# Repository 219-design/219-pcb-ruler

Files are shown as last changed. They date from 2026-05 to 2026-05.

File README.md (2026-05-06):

# 219 PCB Ruler

The 219 PCB Ruler is a multi-disciplinary tool and development platform. Explore this repository to find inspiration for some of the many ways that this ruler can be built out to help you solve problems and create cool projects.

Want to see the projects we've made so far? Check out the [examples folder](firmware/ruler_lib/examples).

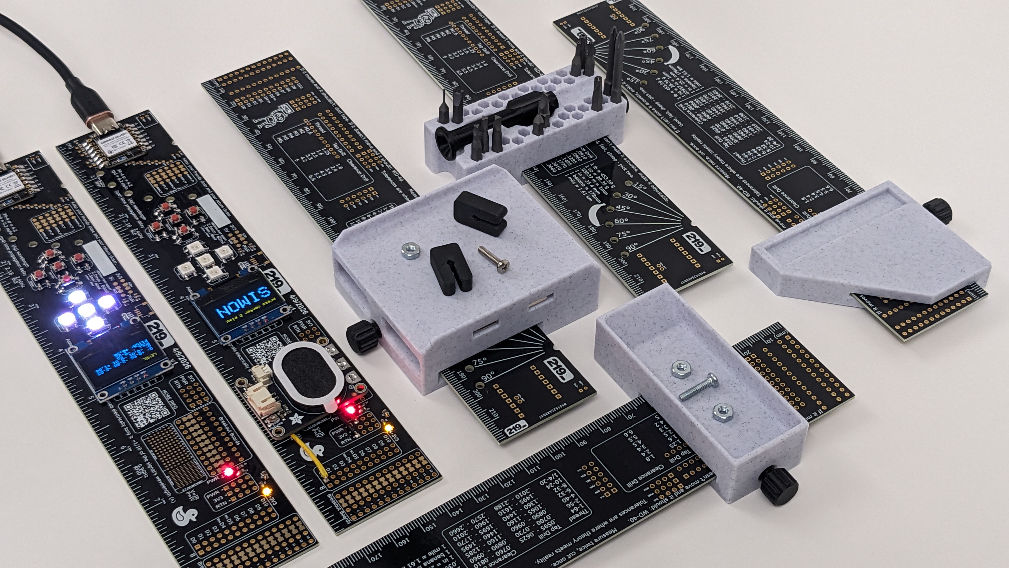
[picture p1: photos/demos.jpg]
Demos


### Known Issues
V1 of the 219 PCB Ruler has the silk screen markings of the battery connector (P17) flipped. BAT+ and BAT- should be swapped. 
Perform a continuity test before using the battery connector to ensure the connections are correct.

## Ways to use the 219 PCB Ruler
### Bare PCB
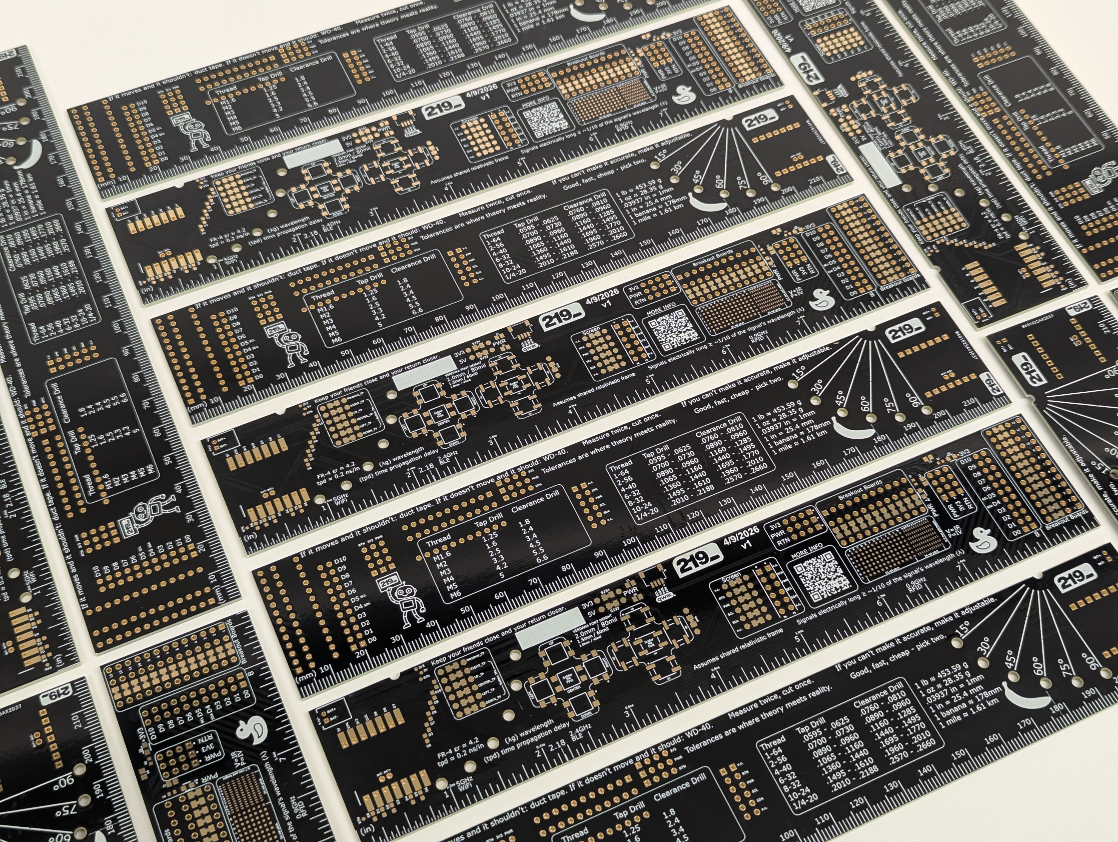
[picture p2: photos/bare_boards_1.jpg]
Bare Boards

- Metric and imperial ruler
- Mechanical and electrical references
- QR code to access additional resources

---

### Electrical Projects
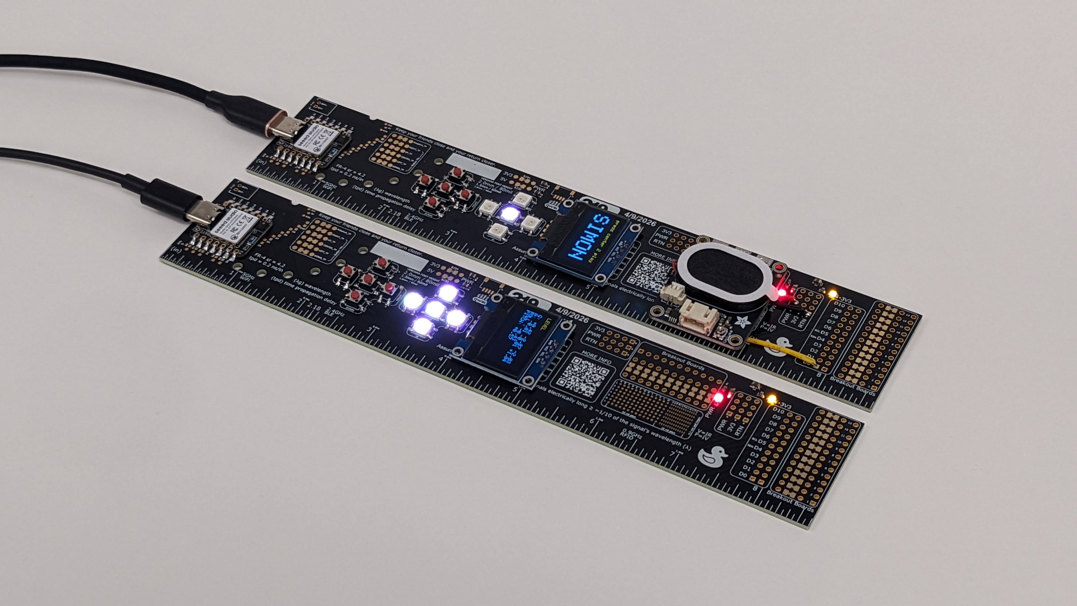
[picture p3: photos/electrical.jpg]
Electrical Demos


Experiment with electronics by soldering on a variety of components to build your own custom projects.  

This board features footprints for:  
- Seeed Studio XIAO Series MCU module  
- Battery connector  
- Button D-pad  
- Neopixels  
- Screen  
- Bypass capacitors  
- Power LEDs  
- QWIIC connector  
- Surface-mount and through-hole protoboard areas  

#### Customization and Flexibility
The board includes **custom solder jumpers** for maximum flexibility.  
- Some jumpers are **normally open**, while others are **normally closed**.  
- These can be used to add series elements or to solder a wire directly to a connection point.  

#### Examples and Resources
Explore our [examples folder](firmware/ruler_lib/examples) for project ideas and wiring diagrams.  

Want to design your own version or order a custom PCB?  
Visit the [electrical folder](electrical) for **Altium design files** and **Gerbers**.  

---

### Mechanical Projects
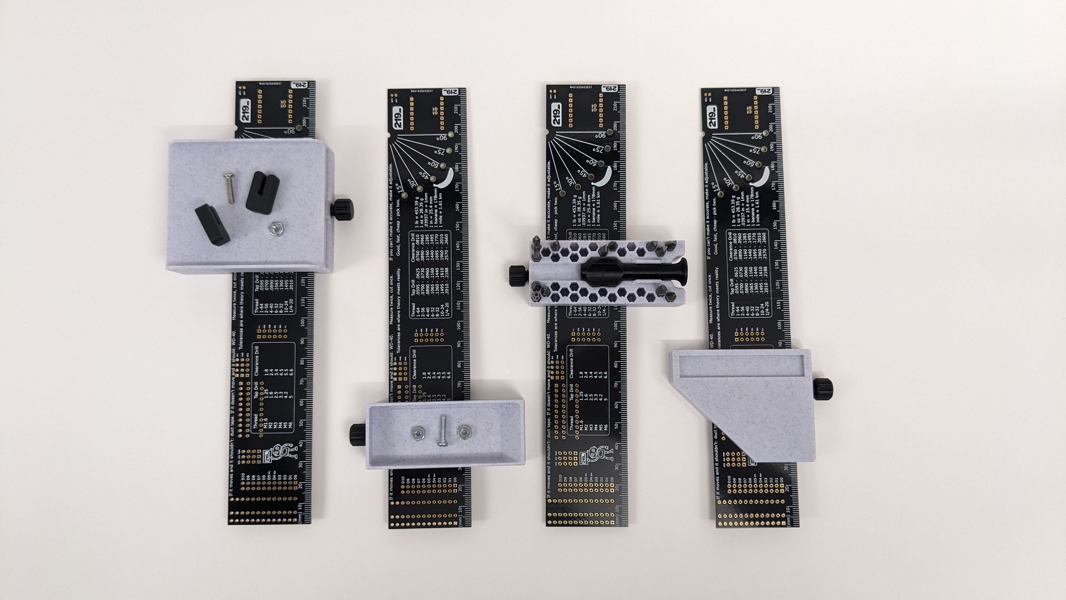
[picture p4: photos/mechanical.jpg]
Mechanical Demos


The PCB ruler is also a great platform for **3D-printed attachments**.  

Weve designed a **3D-printable clamp** that securely grips the ruler and can be adapted for a variety of uses - such as **tool holders**, **marking tools**, or other creative mechanical add-ons.  

Explore our demo designs on [Onshape](https://cad.onshape.com/documents/a66641dbc2e63d92f0bfc751/w/f00ac217e622a64d2a372b85/e/9fa5ab666376091f7bf63026), or browse the [mechanical folder](mechanical) for CAD files and printable models.

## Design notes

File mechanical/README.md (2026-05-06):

# 219 PCB Ruler Mechanical Resources

Explore our demo designs in [Onshape](https://cad.onshape.com/documents/a66641dbc2e63d92f0bfc751/w/f00ac217e622a64d2a372b85/e/9fa5ab666376091f7bf63026). 

Mechanical Demos

This folder is for 3D printable resources and assembly instructions for add-ons to the PCB ruler.

Looking for a design related to an interdisciplinary project? Check out the [examples folder](../firmware/ruler_lib/examples).

---

The PCB ruler is also a great platform for **3D-printed attachments**.  

We've designed a **3D-printable clamp** that securely grips the ruler and can be adapted for a variety of uses - such as **tool holders**, **marking tools**, or other creative mechanical add-ons.  

## Demo Photos
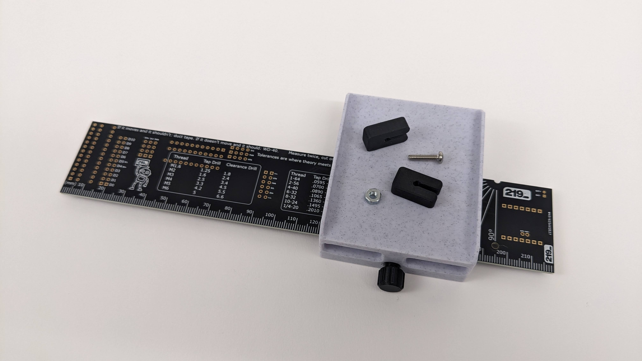
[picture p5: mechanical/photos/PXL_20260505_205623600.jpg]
Storage Large

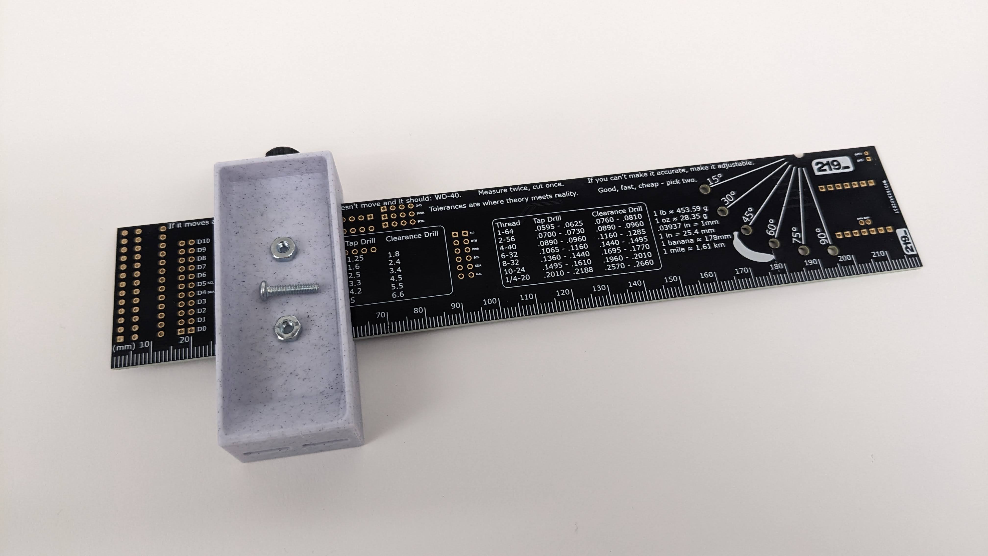
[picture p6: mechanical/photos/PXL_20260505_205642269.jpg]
Storage Small

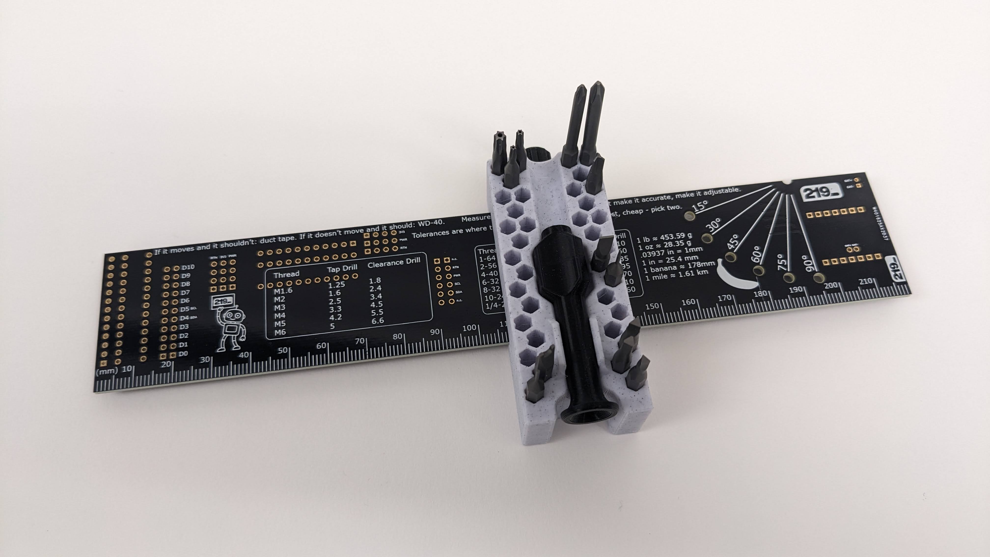
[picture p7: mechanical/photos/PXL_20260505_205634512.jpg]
Screw Driver

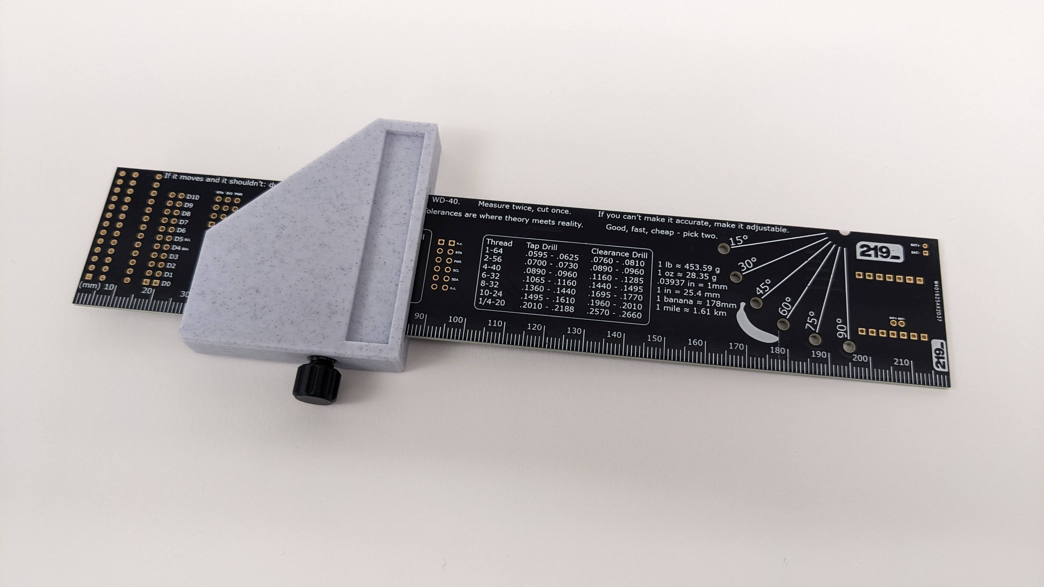
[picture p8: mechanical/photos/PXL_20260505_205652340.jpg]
Marking Tool


## CAD Photos
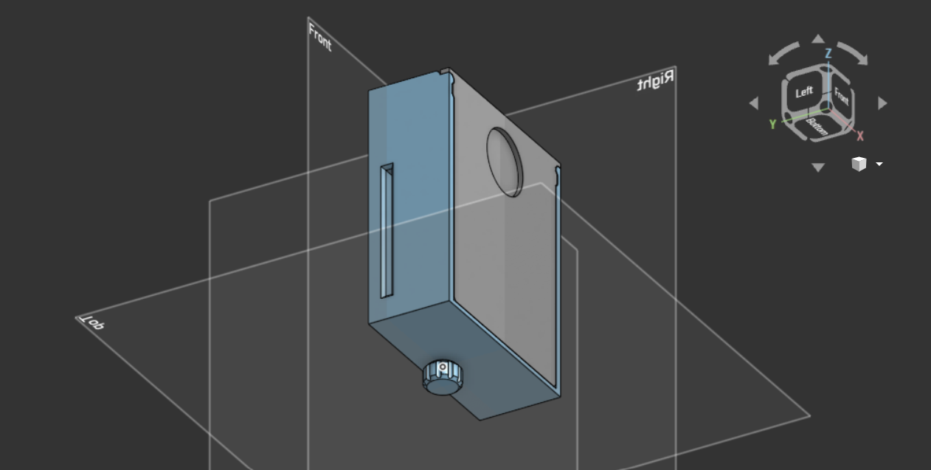
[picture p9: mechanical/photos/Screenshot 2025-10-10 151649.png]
CAD Photo 1

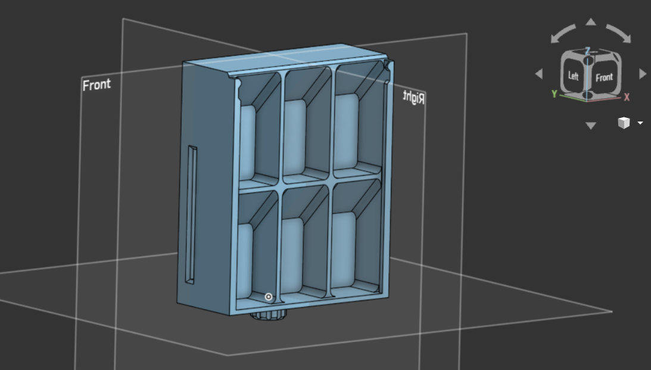
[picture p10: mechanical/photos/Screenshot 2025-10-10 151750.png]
CAD Photo 2

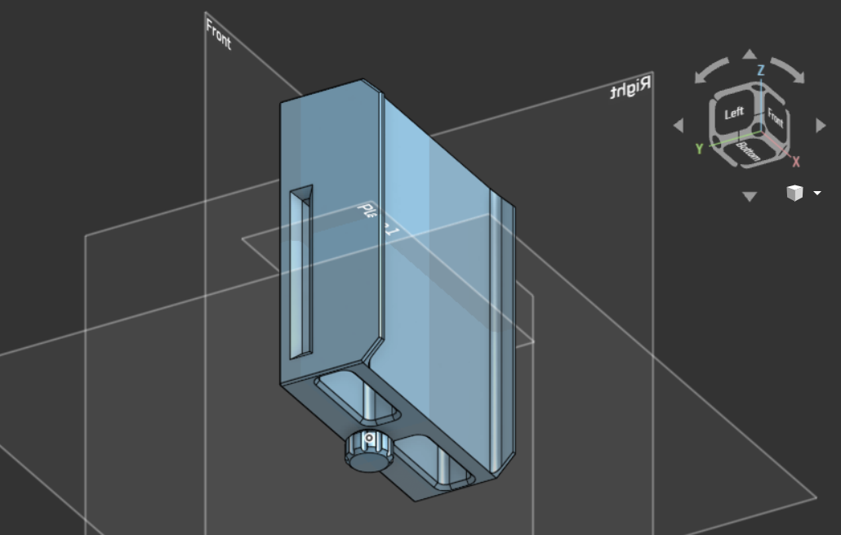
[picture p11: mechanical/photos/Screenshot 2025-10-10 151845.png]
CAD Photo 3

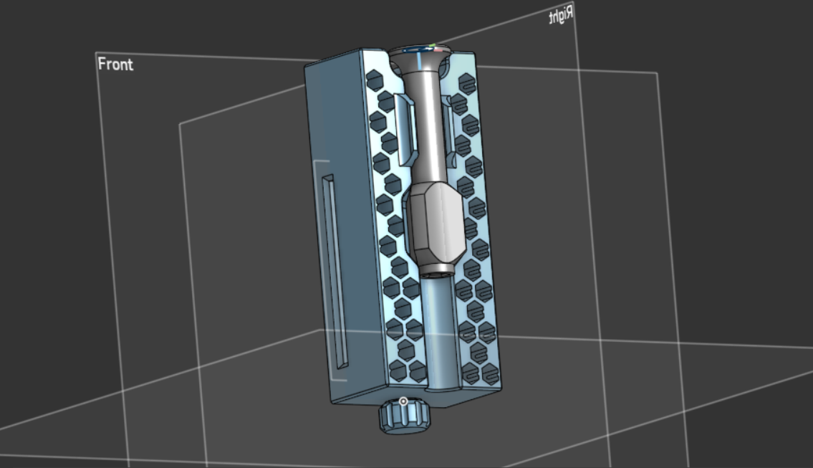
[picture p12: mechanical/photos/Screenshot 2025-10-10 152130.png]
CAD Photo 4

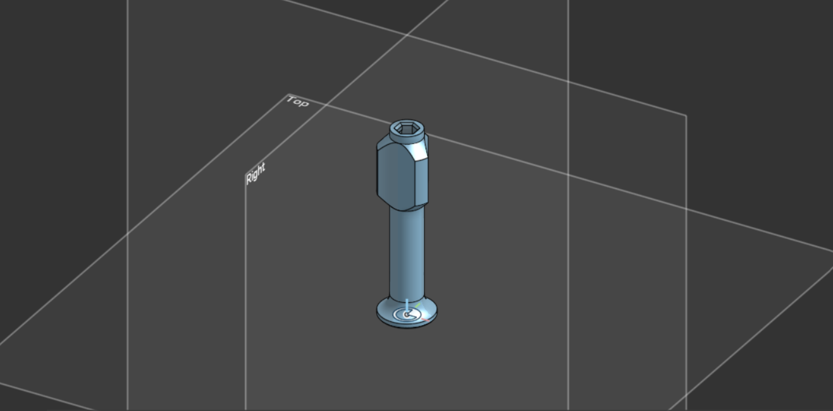
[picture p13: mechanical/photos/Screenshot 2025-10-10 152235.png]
CAD Photo 5

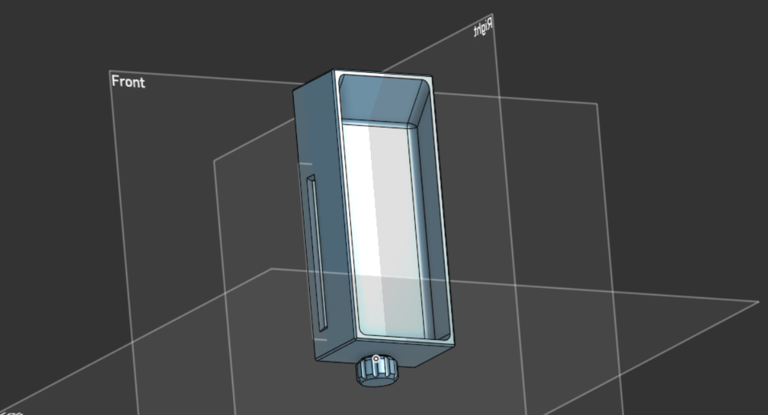
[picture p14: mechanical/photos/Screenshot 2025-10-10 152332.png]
CAD Photo 6


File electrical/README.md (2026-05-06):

# 219 PCB Ruler Electrical Resources
This folder contains everything you need to order, build, and debug the board yourself.

Interested in a specific project? Check out the [examples folder](../firmware/ruler_lib/examples)

### Electrical Projects
Electrical Demos

Experiment with electronics by soldering on a variety of components to build your own custom projects.  

This board features footprints for:  
- Seeed Studio XIAO Series MCU module  
- Battery connector  
- Button D-pad  
- Neopixels  
- Screen  
- Bypass capacitors  
- Power LEDs  
- QWIIC connector  
- Surface-mount and through-hole protoboard areas  

#### Customization and Flexibility
The board includes **custom solder jumpers** for maximum flexibility.  
- Some jumpers are **normally open**, while others are **normally closed**.  
- These can be used to add series elements or to solder a wire directly to a connection point.  

### Assembly
So you have a 219 PCB Ruler and you want to make a cool electrical design. Where do you start?

The board is designed to be used with a [Seeed Studio XIAO Series MCU module](https://www.seeedstudio.com/xiao-series-page).
These modules are all pin compatible, so pick which one has the features you want for your project.
Mount the module to the U1 footprint. The footprint includes options to surface mount solder, TH solder, or TH socket the module. Choose what is best for your project.

Check out the BOM for part recommendations. Check the examples folder for demo specific BOMs.

#### Bypass caps
The board has four footprints (C1-C4) for bypass caps to provide some localized power.

#### Power LEDs
The board has two power LEDs: 5V (D1) and 3V3 (D2). Recommend installing these and their associated current limiting resistors (R1, R2).

#### Want to use use a LiPo battery?
Surface mount solder the MCU to U1 so the BAT- and BAT+ TH pins touch the pads on the bottom of the module.
Solder a connector to P17 and flow solder through the BAT- and BAT+ TH pads to connect the pads to the pads on the bottom of the MCU module.
Choose a battery that meets your project specs and make sure the pinout matches the connector.
Note: the silk screen label for the battery connector on v1 is flipped. See [Known Issues](../README.md#known-issues).

#### Want to use buttons?
Solder buttons to as many of the D-pad button pads as you would like. Make sure to solder the center button first if you want to use it since it will be harder to solder it after installing the outer buttons.
The buttons short to return on press. The circuit doesn't include a pull up or debouncing circuit so recommend implementing this in firmware.

#### Want to use Neopixels?
Solder Neopixels to as many of the pads as you would like (U2, U3, U4, U5, U6). Note that Neopixels works on single wire communication and ours are connected in numerical order. So if you would like to use only one Neopixel, use U2. Otherwise you will need to short the input and output pins across the unused Neopixels in the chain before the one you want to use in order for the signal to reach a pad later in the chain.

#### Want to use a Screen?
Ideally pick a screen with a pinout that matches the silk on the board. See the BOM for the one we used.
If you have a different I2C screen that you would like to use but it has a different pinout for it's 100mil header, you can reconfigure the pinout by cutting the custom jumpers under the pin. Then use the surface mount or through hole pads to wire up the correct pinout with some jumper wire.
Solder your screen into either P8 or P9. 

#### Want to use a QWIIC module?
Solder a QWIIC connector to J1 and plug in any QWIIC module. This footprint is already wired up to power and I2C so it is ready to go.

#### Have a 100mil header sensor module?
There are two 100mil header breakout board sections on the board. Just solder your module to the last row of TH headers and then solder a wire from either side of the custom jumper to the desired power, return, or IO pins.
See our demos for an examples of this.

#### Have other parts?
Use one of the three breakout areas to solder TH or SMT components. Use jumper wire to connect the pins to the appropriate IO and power signals.

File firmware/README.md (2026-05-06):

# ME218 PCB Ruler Firmware Resources
This folder contains firmware examples for basic component functionality.

## Ruler Lib

The Ruler Lib is small collection of classes for using some of the hardware features of the ruler board. 

### Installing Ruler Lib

Open the Arduino IDE. 

Select: Sketch Menu >> Include Library >> Add .ZIP library...

In the file dialog, find the ruler_lib.zip file

This will install the ruler_lib to use with sketches

### Editing the Ruler Lib

If you'd like to make changes to the lib, you can modify the files in the src folder. Then compress the entire "ruler_lib" directory into a zip file and (re)install the new library from zip as described above.

### Included Examples

All examples in this repository are included in the Arduino IDE when the Ruler Lib is installed. To open an example from the IDE, such as the Simon Game example:

Select: File >> Examples >> ruler_lib >> simon_says

Any dependent libraries are noted with the github repository in the example code.

### Seed XIAO Boards 

Install Seed XIAO Board packages as instructed by:
https://wiki.seeedstudio.com/XIAO_BLE/#getting-started

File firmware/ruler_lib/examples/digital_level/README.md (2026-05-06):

# ME218 PCB Ruler - Digital Level 

This sketch creates a digital level, utilizing the IMU on the XIAO-nRF52840 board. Gyroscope and accelerometer readings are displayed on the OLED screen, along with roll and pitch angles. A complementary filter is used for approximation of pitch/roll angles. The LEDs will indicate white for levelness in the appropriate direction, and a graduated scale of color (purple to red) for the direction of positive slope.

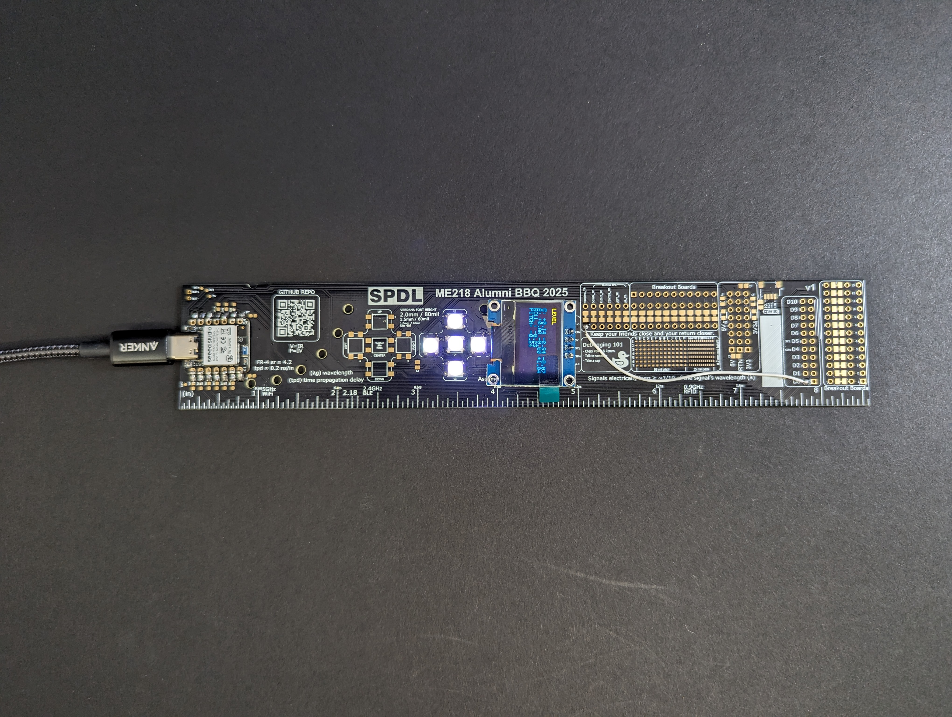
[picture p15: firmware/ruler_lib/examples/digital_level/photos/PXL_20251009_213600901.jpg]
level


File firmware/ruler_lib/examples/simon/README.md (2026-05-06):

# ME218 PCB Ruler - Simon

This sketch is a working example of the Simon game by Milton Bradley (now Hasbro). 
Simon is a registered trademark of Hasbro, Inc. This project is not affiliated with or endorsed by Hasbro.

The game begins by pressing the center button. Each round, a colored led will light and the associated tone will play. The player then copies the pattern by pressing the button associated with the led.
The next round will play back the previous light, along with another one. The player copies the pattern again, adding in the new one at the end.
As rounds go by, the speed of the pattern presentation will increase. There are 30 rounds of play. If the player enters an incorrect entry, the game is over.

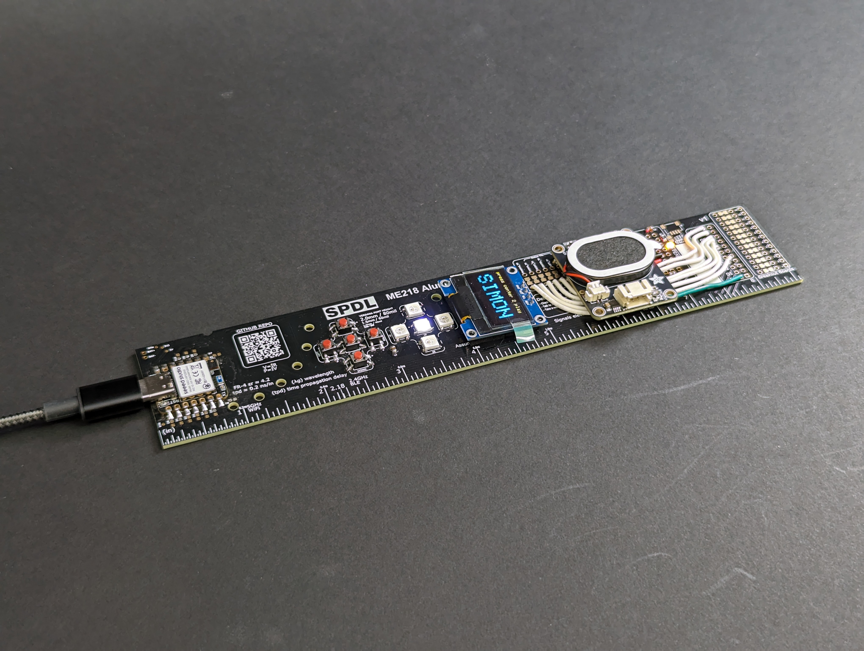
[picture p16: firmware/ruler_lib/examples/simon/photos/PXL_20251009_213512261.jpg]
simon


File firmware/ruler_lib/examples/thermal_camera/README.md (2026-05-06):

# 219 PCB Ruler - Thermal Camera - COMING SOON

This sketch creates a thermal camera utilizing a thermal sensor and 1.44" tft. This sketch was extended from Adafruit's examples for their AMG88xx GridEYE 8x8 IR camera but made to work with a different tft display. 

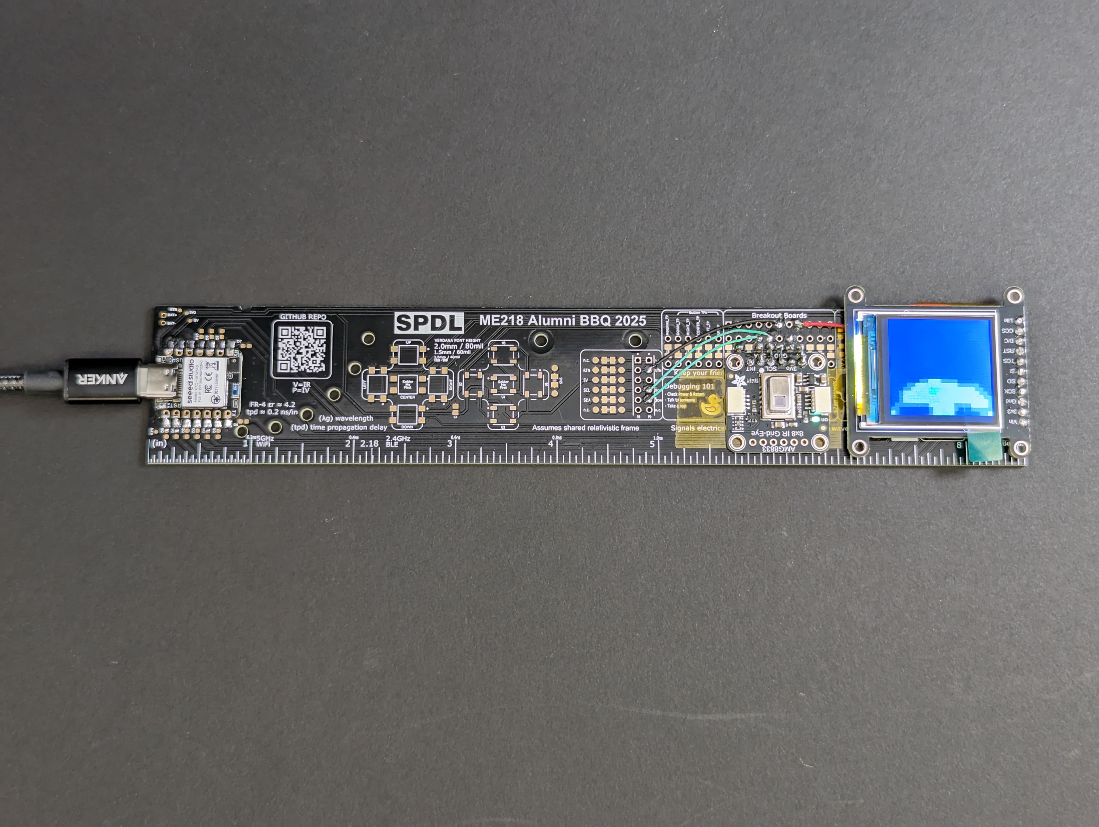
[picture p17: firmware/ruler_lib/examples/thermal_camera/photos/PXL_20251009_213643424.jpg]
thermal


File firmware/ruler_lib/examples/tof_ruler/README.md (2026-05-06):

# 219 PCB Ruler - ToF Ruler - COMING SOON

This sketch creates line of sight digital ruler utilizing a time of flight sensor. Distances measured from the sensor will be displayed on the OLED screen. Pressing the button will change units from imperial to metric. Distances greater than 5400mm are outside of the sensors operating range and will not be accurate.

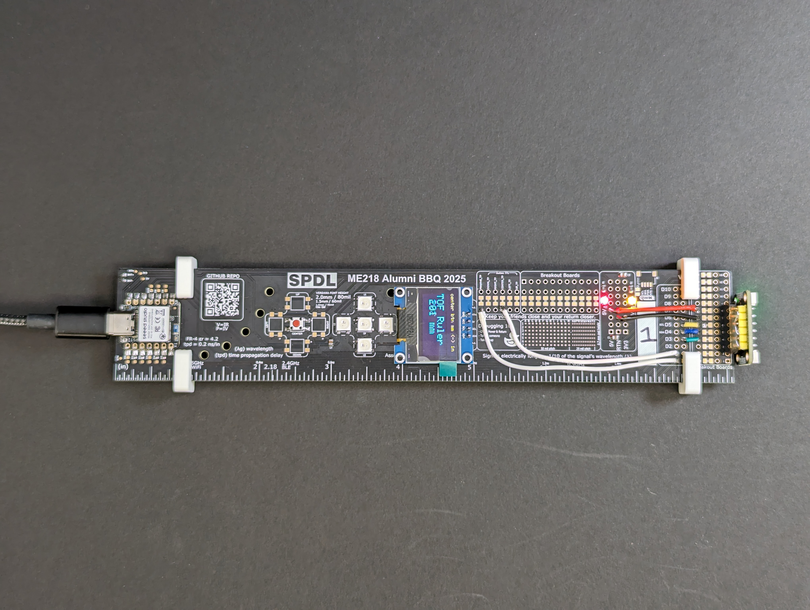
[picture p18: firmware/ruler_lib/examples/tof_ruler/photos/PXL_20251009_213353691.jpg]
tof


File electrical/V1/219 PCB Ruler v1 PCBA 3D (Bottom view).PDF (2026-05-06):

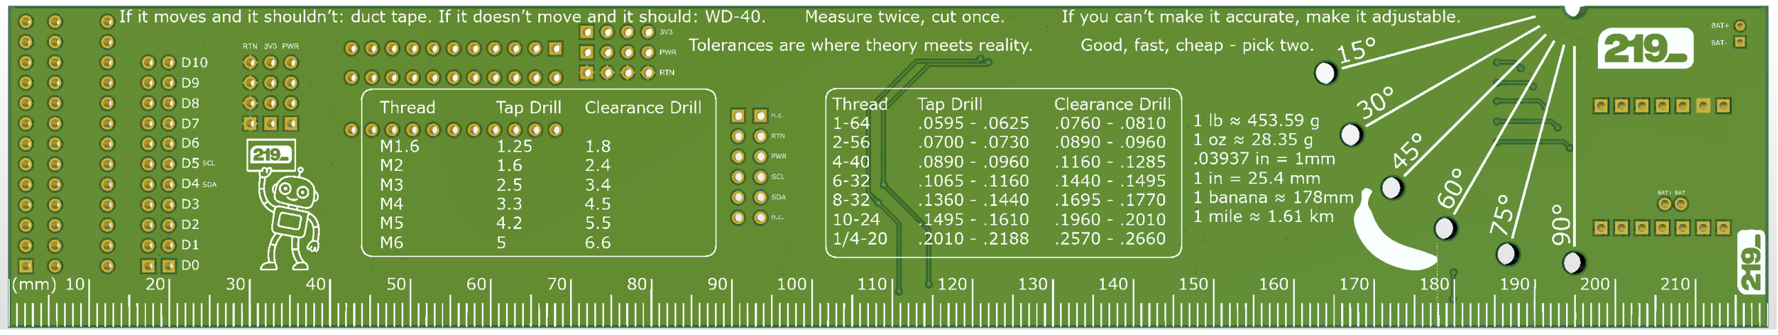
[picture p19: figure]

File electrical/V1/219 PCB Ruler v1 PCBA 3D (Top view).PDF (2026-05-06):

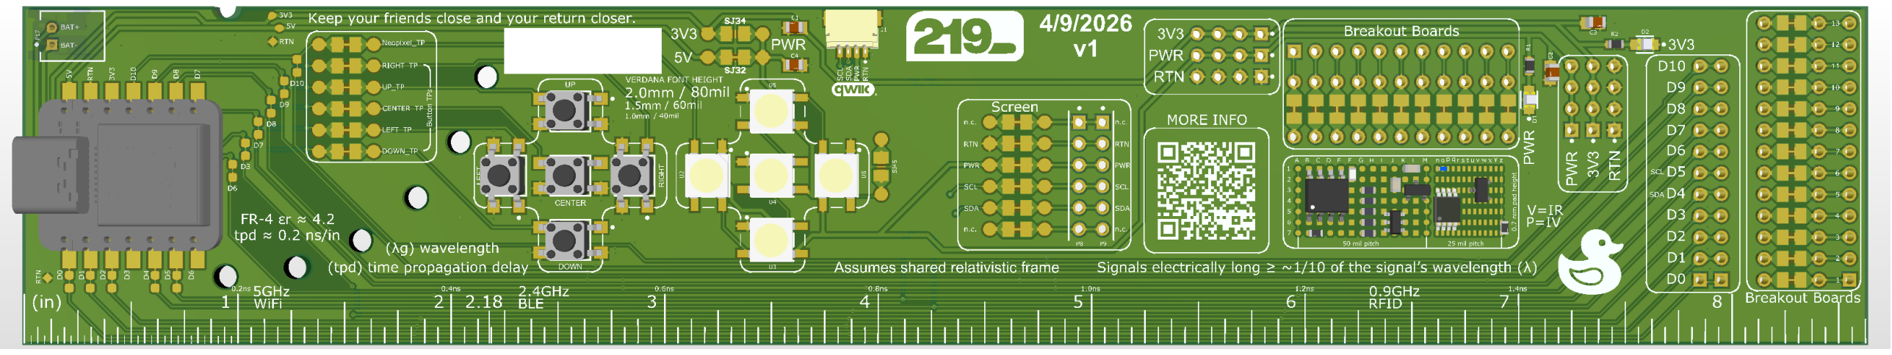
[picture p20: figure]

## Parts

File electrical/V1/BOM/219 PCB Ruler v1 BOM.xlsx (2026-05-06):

 | Bill of Materials
 | Project Name: | 219 PCB Ruler
 | Report Date: | 4/9/2026 | 15:21
 | Engineer: | 219 Design
 | BOM Revision History
 | Version | Date | Description
 | v1 | 4/9/2026 | Initial release
# | Designator | Description | Manufacturer 1 | Manufacturer Part Number 1 | Supplier 1 | Supplier Part Number 1 | Fitted | Footprint | Quantity
1 | R1, R2 | SMD Chip Resistor, 330 Ohm, ± 1%, 100 mW, 0603 [1608 Metric], Thick Film, General Purpose | Yageo Group | RC0603FR-07330RL | DigiKey | 311-330HRCT-ND | Fitted | RESC1608X55X25NL10T15 | 2
2 | U2-U6 | NeoPixel 5050 RGB LED with Integrated Driver Chip - 10 Pack | Adafruit Industries 1655 | Adafruit Industries | 1655 | DigiKey | 1528-1104-ND | Fitted | ADA-RGB-1655_V | 5
3 | C1-C4 | Multilayer Ceramic Capacitor, 1 uF, 50 V, ± 10%, X7R, 0805 [2012 Metric] | Murata | GCM21BR71H105KA03K | DigiKey | 490-13310-1-ND | Fitted | FP-GRM21B-0_15-IPC_B | 4
4 | D1 | 0805 Single Color LED, Super Red, Colorless Diffused, 1.3mm | Osram | LS R976-NR-1 | Mouser | 720-LSR976-NR-1 | Fitted | FP-LS_R976-MFG | 1
5 | D2 | 0805 Single Color LED, Yellow, Colorless Diffused, 1.3mm | Osram | LY R976-PS-36 | Mouser | 720-LYR976-PS-36 | Fitted | FP-LS_R976-MFG | 1
6 | CENTER, DOWN, LEFT, RIGHT, UP | Keypad Switch, 1 Switches, SPST, Momentary-tactile, 0.05A, 12VDC, 2.45N, Solder Terminal, Surface Mount-straight | E-Switch | TL3305AF260QG | DigiKey | EG5353CT-ND | Fitted | FP-TL3305AF260QG-MFG | 5
7 | P17 | Header for PCB; pitch 2.00mm; 2-contacts; THT; male; side entry; 100V/2A | JST | S2B-PH-K-S(LF)(SN) | Newark | S2B-PH-K-S (LF)(SN) | Fitted | JST-S2B-PH-K-S_V | 1
8 | U1 | Seeed studio XIAO series dev boards | Seeed Studio | 102010428 | DigiKey | 1597-102010428-ND | Fitted | Seeeduino XIAO-Footprint-Both | 1
9 | J1 | QWIIC JST CONNECTOR - SMD 4-PIN | SparkFun | 14417 | DigiKey | 1568-14417-ND | Fitted | SPARKFUN_PRT-14417 | 1
10 | P8 | Screen | ELEGOO | EL-SM-008 | Amazon | EL-SM-008 | Fitted | HDR 06 POS 100mil 2.54mm | 1
 |  |  |  |  |  |  |  |  | 22
Notes

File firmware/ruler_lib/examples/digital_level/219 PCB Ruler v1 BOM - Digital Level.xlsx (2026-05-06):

 | Bill of Materials
 | Project Name: | 219 PCB Ruler
 | Report Date: | 5/4/2026 | 17:09
 | Engineer: | 219 Design
 | BOM Revision History
 | Version | Date | Description
 | v1 | 5/4/2026 | Initial release
# | Designator | Description | Manufacturer 1 | Manufacturer Part Number 1 | Supplier 1 | Supplier Part Number 1 | Fitted | Footprint | Quantity
1 | C1-C4 | Multilayer Ceramic Capacitor, 1 uF, 50 V, ± 10%, X7R, 0805 [2012 Metric] | Murata | GCM21BR71H105KA03K | DigiKey | 490-13310-1-ND | Fitted | FP-GRM21B-0_15-IPC_B | 4
2 | CENTER, DOWN, LEFT, RIGHT, UP | Keypad Switch, 1 Switches, SPST, Momentary-tactile, 0.05A, 12VDC, 2.45N, Solder Terminal, Surface Mount-straight | E-Switch | TL3305AF260QG | DigiKey | EG5353CT-ND | Not Fitted | FP-TL3305AF260QG-MFG | 0
3 | D1 | 0805 Single Color LED, Super Red, Colorless Diffused, 1.3mm | Osram Opto | LS R976-NR-1 | Mouser | 720-LSR976-NR-1 | Fitted | FP-LS_R976-MFG | 1
4 | D2 | 0805 Single Color LED, Yellow, Colorless Diffused, 1.3mm | Osram | LY R976-PS-36 | Mouser | 720-LYR976-PS-36 | Fitted | FP-LS_R976-MFG | 1
5 | J1 | QWIIC JST CONNECTOR - SMD 4-PIN | SparkFun | 14417 | DigiKey | 1568-14417-ND | Not Fitted | SPARKFUN_PRT-14417 | 0
6 | P17 | Header for PCB; pitch 2.00mm; 2-contacts; THT; male; side entry; 100V/2A | JST | S2B-PH-K-S(LF)(SN) | Future Electronics | 7754757 | Not Fitted | JST-S2B-PH-K-S_V | 0
7 | R1, R2 | SMD Chip Resistor, 330 Ohm, ± 1%, 100 mW, 0603 [1608 Metric], Thick Film, General Purpose | Yageo Group | RC0603FR-07330RL | DigiKey | 311-330HRCT-ND | Fitted | RESC1608X55X25NL10T15 | 2
8 | U1 | Seeed studio XIAO series dev boards | Seeed Studio | XIAO nRF52840 Sense | DigiKey | 1597-102010469-ND | Fitted | Seeeduino XIAO-Footprint-Both | 1
9 | U2-U6 | NeoPixel 5050 RGB LED with Integrated Driver Chip - 10 Pack | Adafruit Industries 1655 | Adafruit Industries | 1655 | DigiKey | 1528-1104-ND | Fitted | ADA-RGB-1655_V | 5
10 | P8 | Screen | ELEGOO | EL-SM-008 | Amazon | EL-SM-008 | Fitted | HDR 06 POS 100mil 2.54mm | 1
11 | NA | Jumper wire | Sparkfun | 11367 | DigiKey | 1568-11367-ND | Fitted | NA | 1
 |  |  |  |  |  |  |  |  | 16
Notes

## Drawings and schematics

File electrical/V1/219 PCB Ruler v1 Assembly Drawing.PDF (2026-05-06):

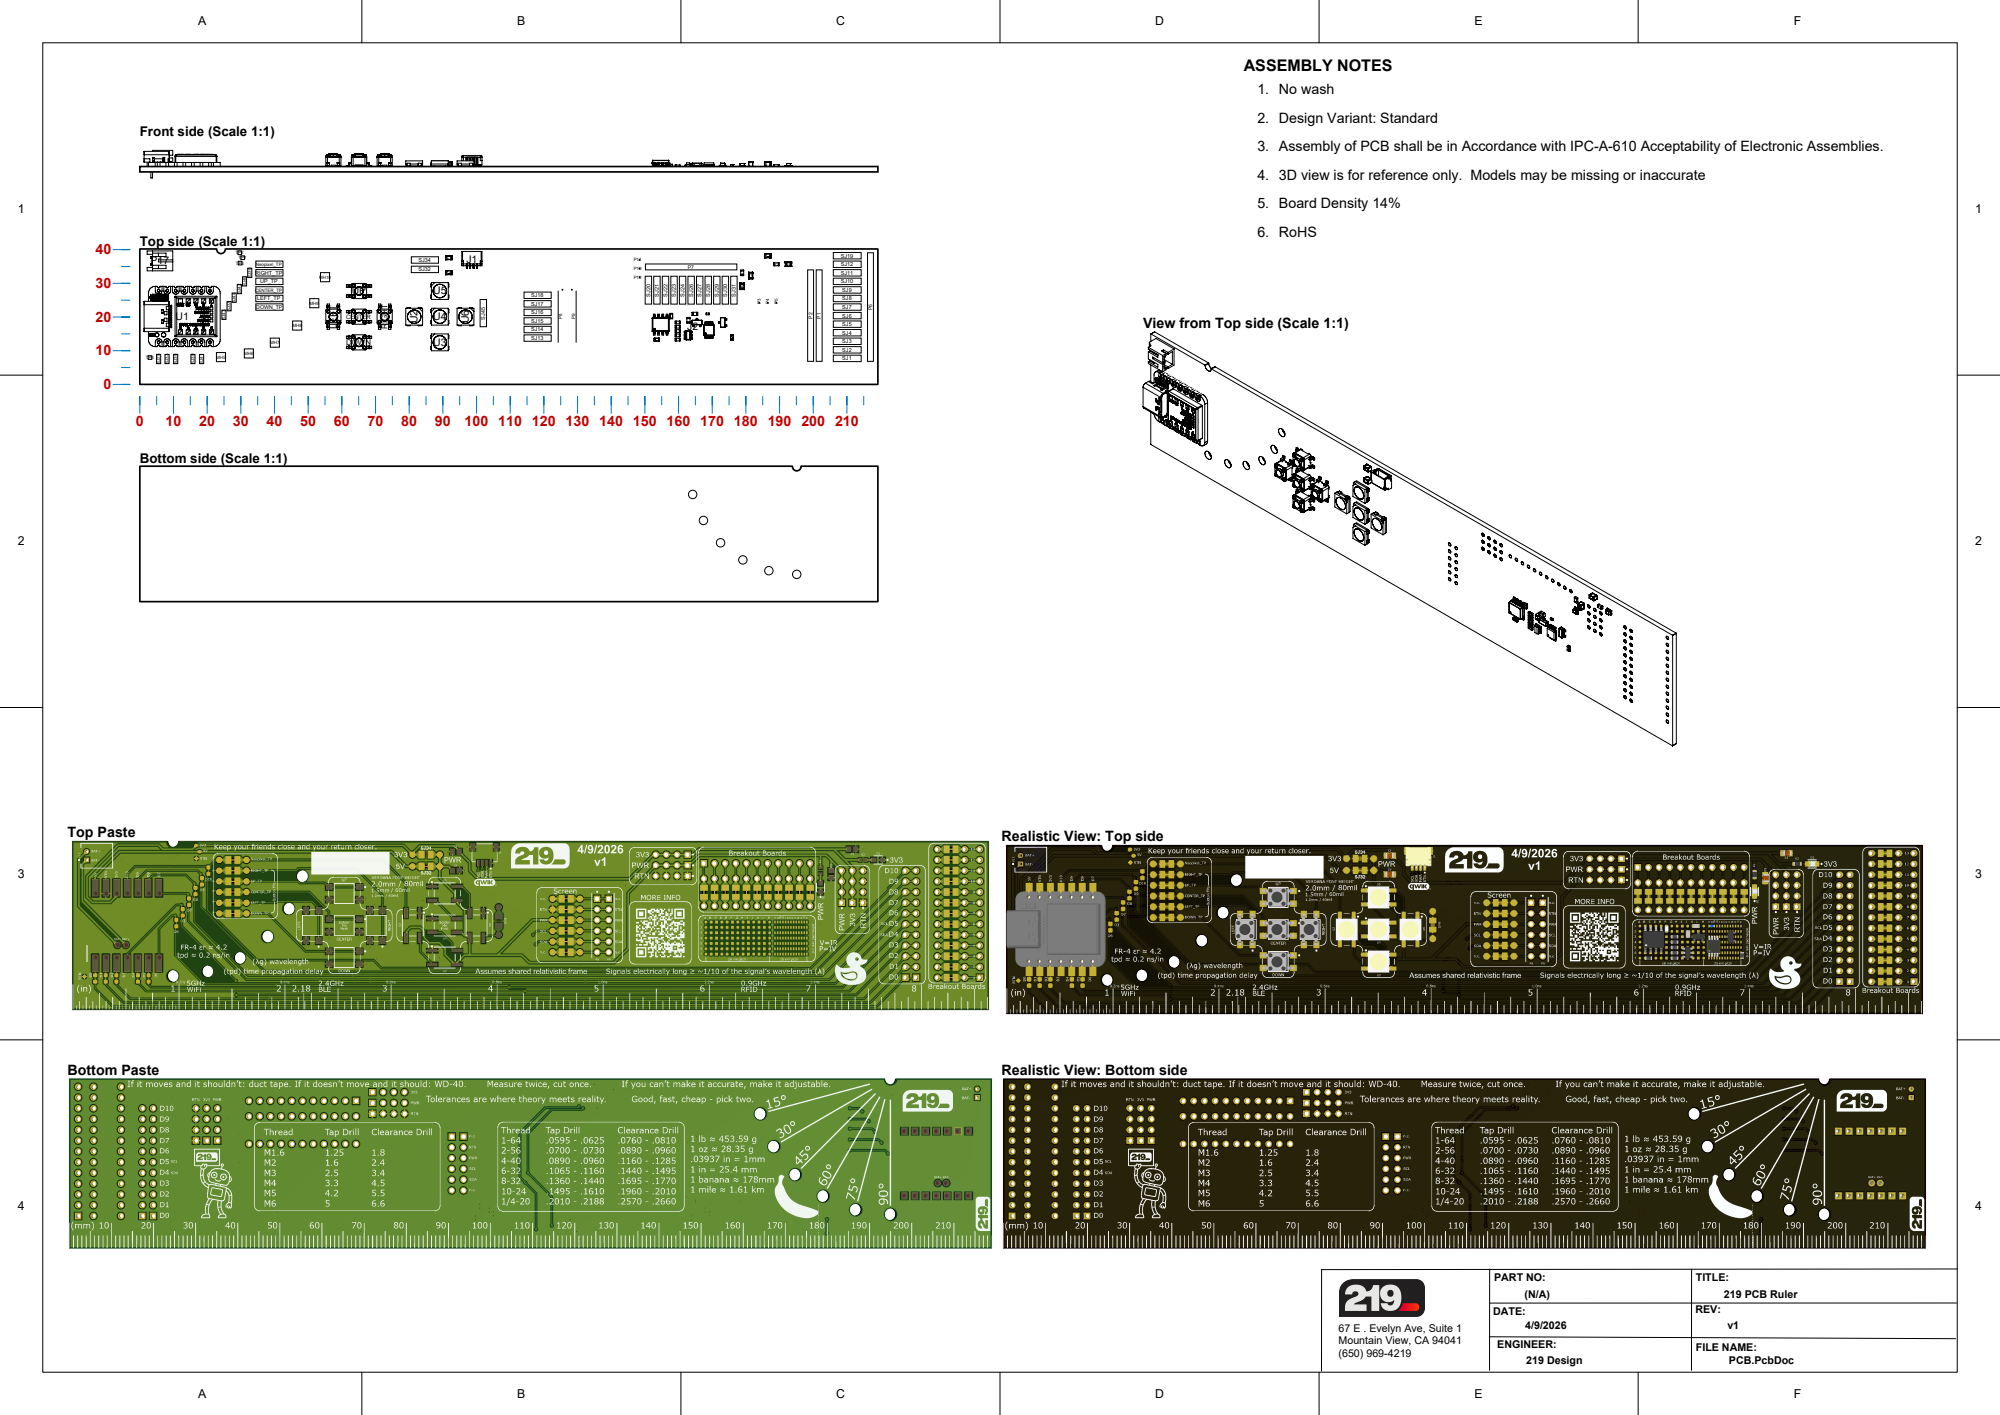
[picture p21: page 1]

ASSEMBLY NOTES
1. No wash
2. Design Variant: Standard
3. Assembly of PCB shall be in Accordance with IPC-A-610 Acceptability of Electronic Assemblies.
4. 3D view is for reference only. Models may be missing or inaccurate
5. Board Density 14%
6. RoHS

View from Top side (Scale 1:1)

Realistic View: Bottom side

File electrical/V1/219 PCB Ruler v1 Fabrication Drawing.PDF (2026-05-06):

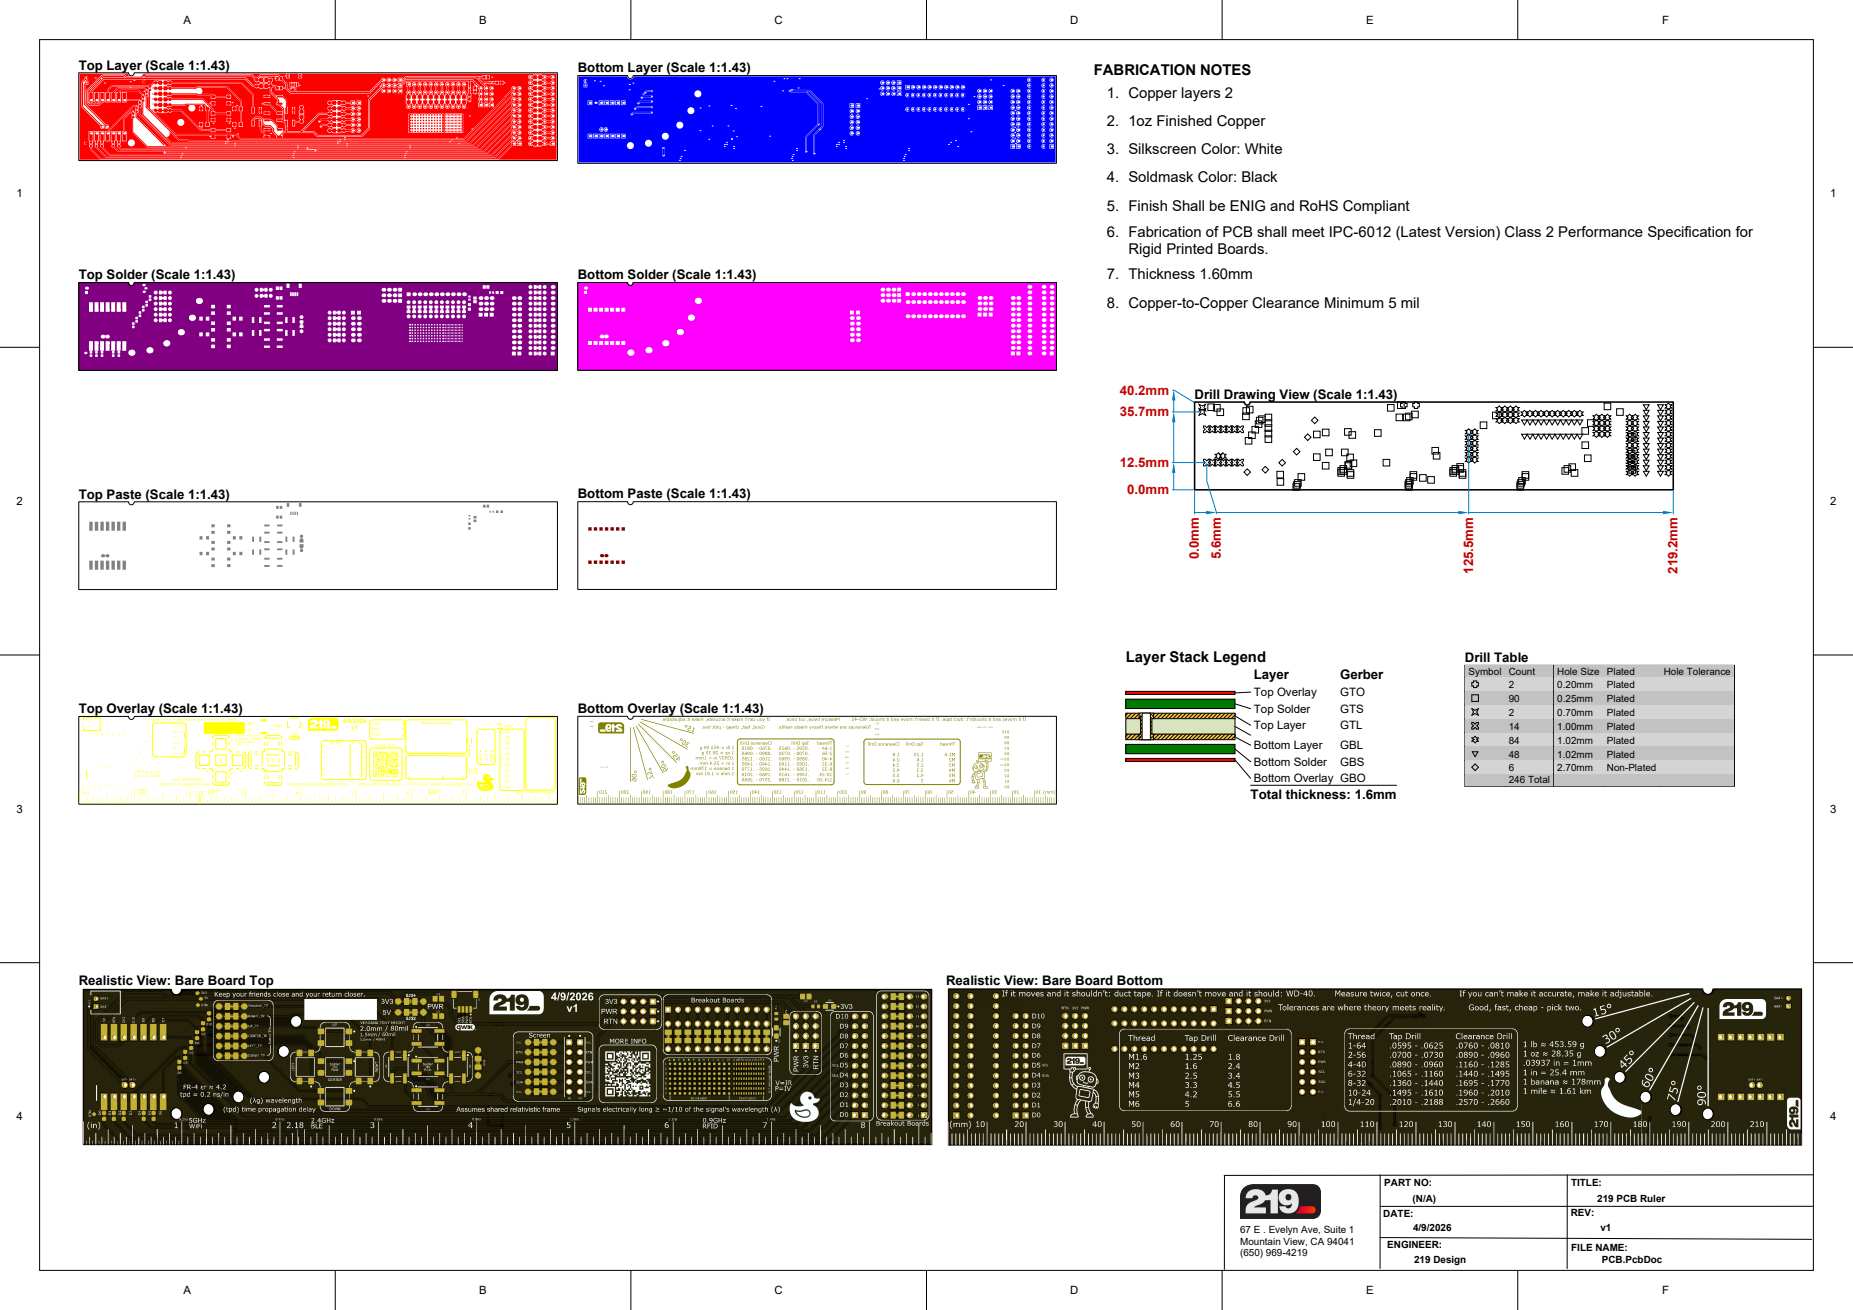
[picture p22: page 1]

FABRICATION NOTES
1. Copper layers 2
2. 1oz Finished Copper
3. Silkscreen Color: White
4. Soldmask Color: Black
5. Finish Shall be ENIG and RoHS Compliant
Fabrication of PCB shall meet IPC-6012 (Latest Version) Class 2 Performance Specification for
Rigid Printed Boards.
7. Thickness 1.60mm
8. Copper-to-Copper Clearance Minimum 5 mil

Drill Drawing View (Scale 1:1.43)

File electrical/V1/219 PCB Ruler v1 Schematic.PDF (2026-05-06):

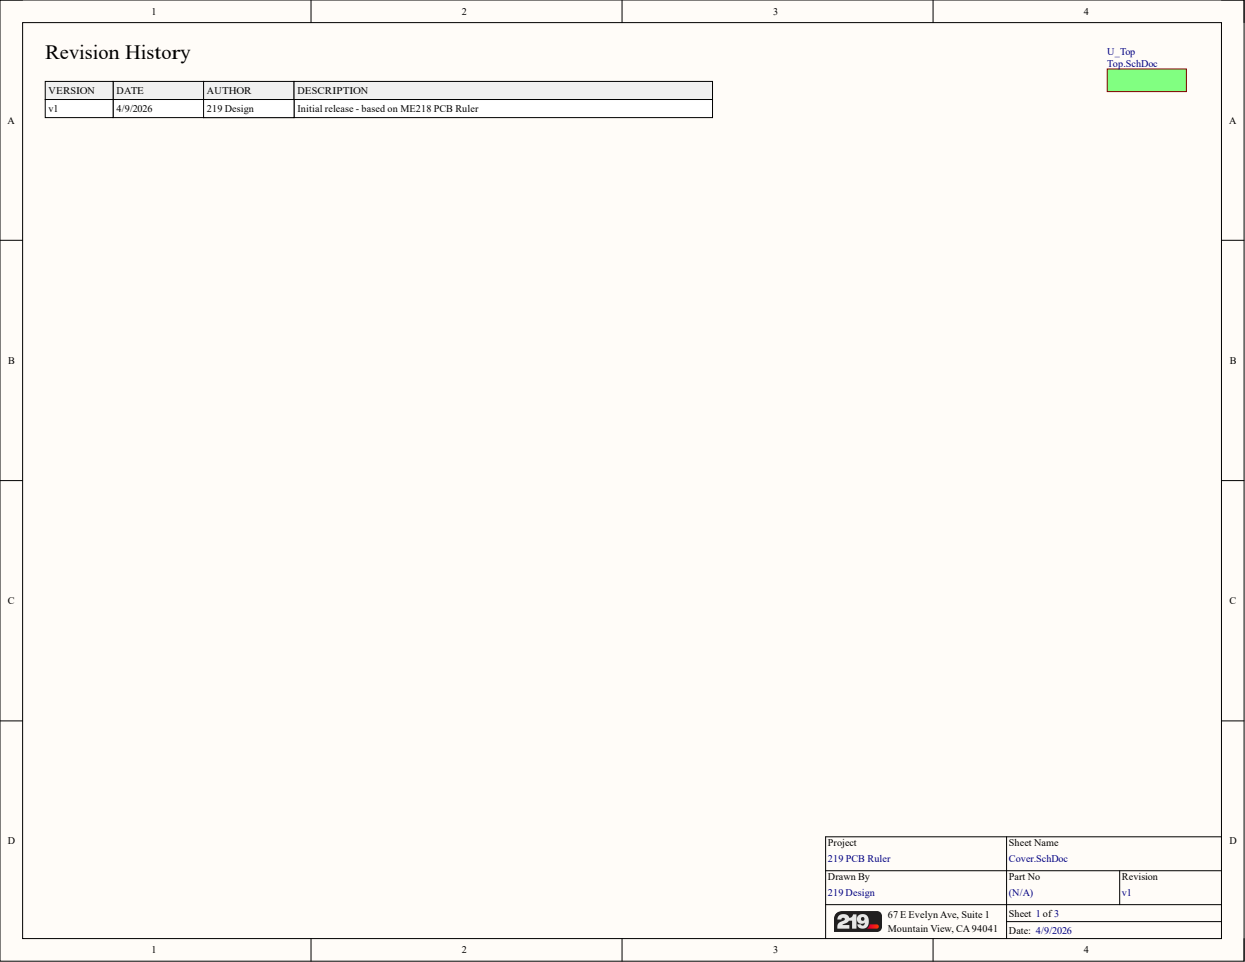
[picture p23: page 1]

VERSION | DATE | AUTHOR | DESCRIPTION
v1 | 4/9/2026 | 219 Design | Initial release - based on ME218 PCB Ruler

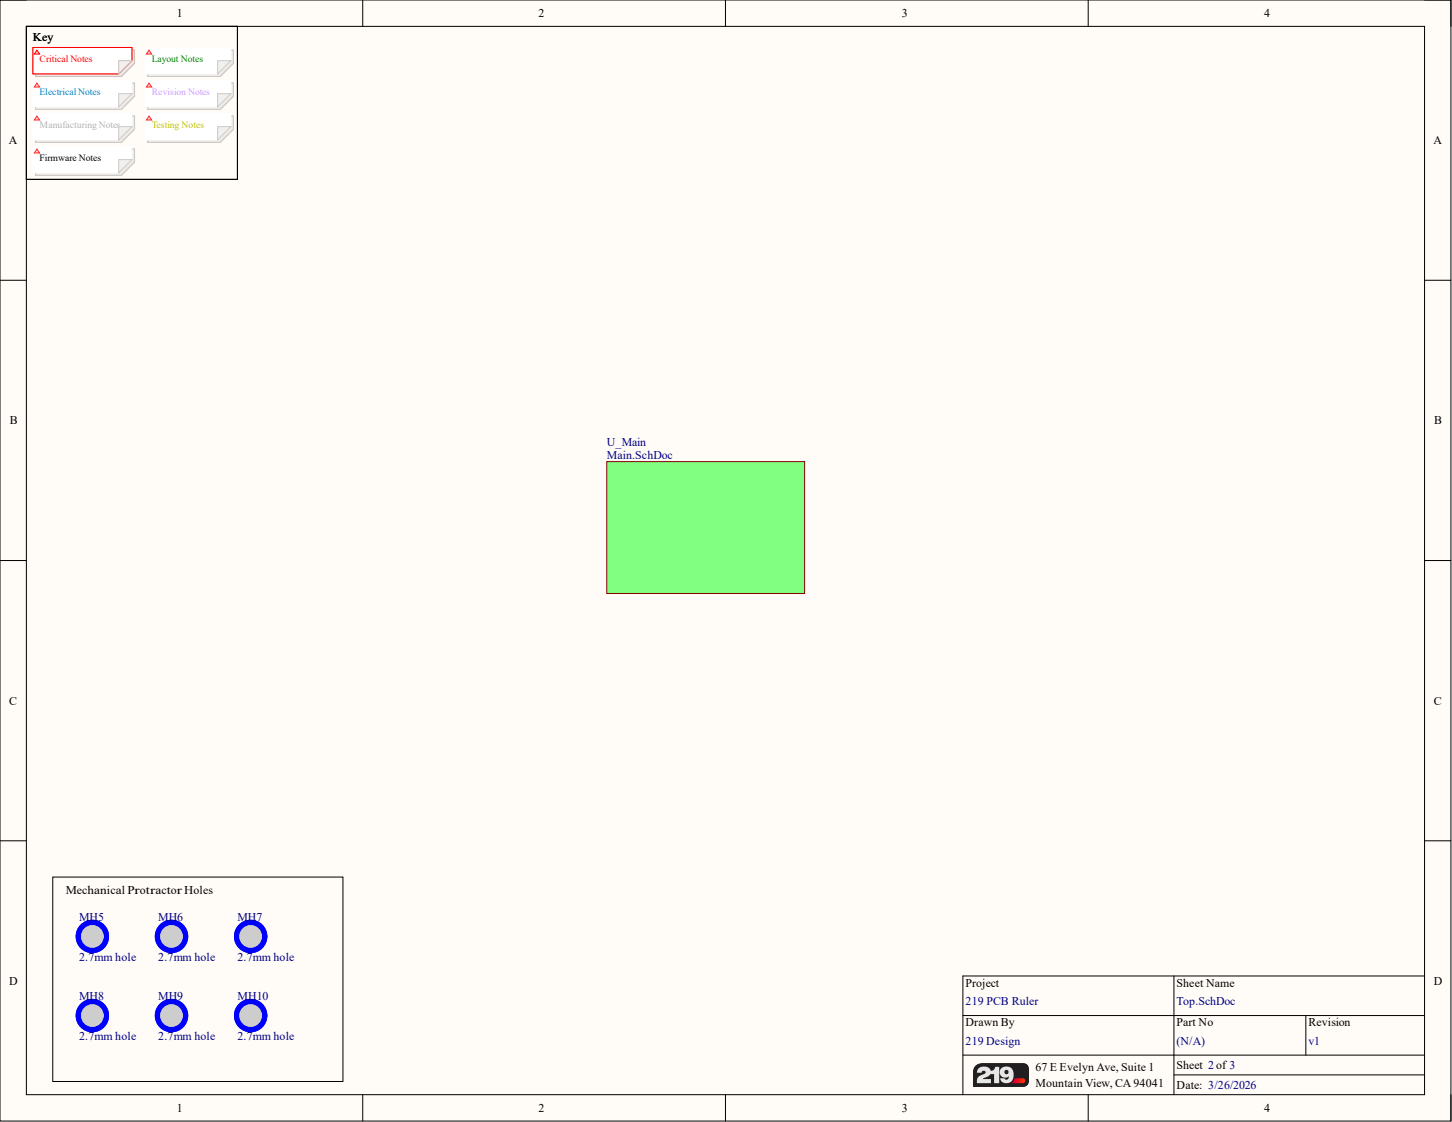
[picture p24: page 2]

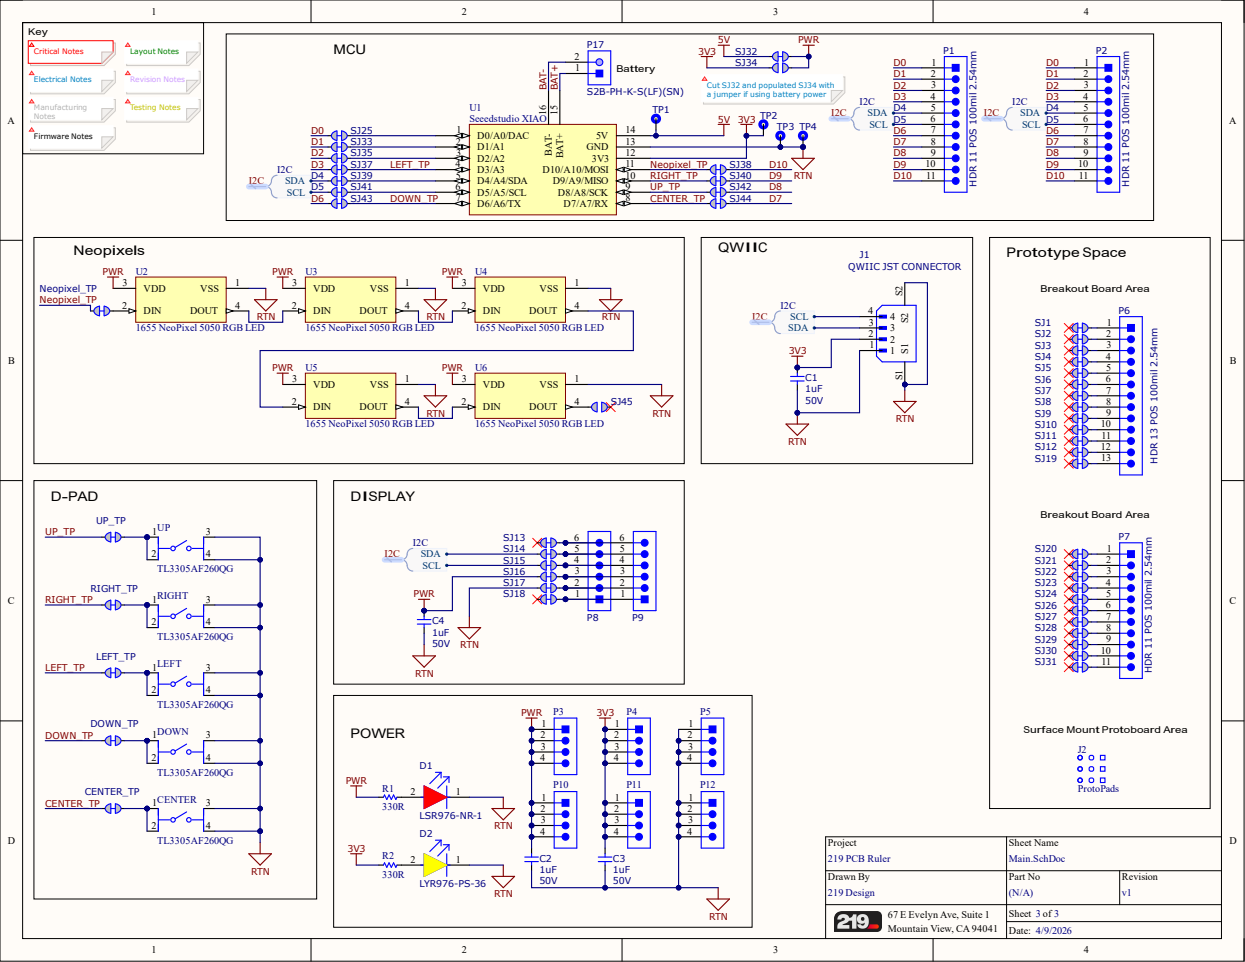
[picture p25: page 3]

S2B-PH-K-S(LF)(SN) BAT+

Cut SJ32 and populated SJ34 with
a jumper if using battery power

Surface Mount Protoboard Area

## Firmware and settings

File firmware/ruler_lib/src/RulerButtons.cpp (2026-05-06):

#include "RulerButtons.h"

#include <Arduino.h>

Buttons::Buttons(int center_btn_pin, int left_btn_pin, int right_btn_pin, int up_btn_pin, int down_btn_pin) {

  m_btn_pin[CENTER_BTN_IDX] = center_btn_pin;
  m_btn_pin[LEFT_BTN_IDX] = left_btn_pin;
  m_btn_pin[RIGHT_BTN_IDX] = right_btn_pin;
  m_btn_pin[UP_BTN_IDX] = up_btn_pin;
  m_btn_pin[DOWN_BTN_IDX] = down_btn_pin;

  for (int i = 0; i < NUM_BTNS; ++i) {
    if (m_btn_pin[i] != INVALID_PIN) {
      pinMode(m_btn_pin[i], INPUT_PULLUP);
    }

    m_last_btn_rd[i] = BTN_DEASSERT_LEVEL;
    m_last_btn_debounce_time[i] = 0;
    m_debounce_btn_val[i] = 0;
  }
}

//returns a set of debounce button states indicated by masks
uint32_t Buttons::get_presses() {
  uint8_t ret_mask = 0;
  for (int idx = 0; idx < NUM_BTNS; ++idx) {
    uint32_t now = millis();
    int rd = m_btn_pin[idx] != INVALID_PIN ? digitalRead(m_btn_pin[idx]) : BTN_DEASSERT_LEVEL;
    if (rd != m_last_btn_rd[idx]) {
      // Serial.printf("btn: %d : %d\r\n", idx, rd);
      m_last_btn_debounce_time[idx] = now;
    }
    m_last_btn_rd[idx] = rd;

    if ((now - m_last_btn_debounce_time[idx]) > c_debounceDelay) {
      //update m_debounce_btn_val
      if (m_debounce_btn_val[idx] != (rd == BTN_ASSERT_LEVEL)) {
        m_debounce_btn_val[idx] = (rd == BTN_ASSERT_LEVEL);
        // Serial.printf("db: %d : %d\r\n", idx, m_debounce_btn_val[idx]);
      }
    }

    //add to return
    ret_mask |= m_debounce_btn_val[idx] << idx;
  }
  return ret_mask;
}

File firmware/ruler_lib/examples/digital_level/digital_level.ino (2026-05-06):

#include <LSM6DS3.h>
//https://github.com/Seeed-Studio/Seeed_Arduino_LSM6DS3/

#include <ruler.h>

#include <Adafruit_NeoPixel.h>
//https://github.com/adafruit/Adafruit_NeoPixel

#include <Adafruit_GFX.h>
#include <Adafruit_SSD1306.h>
// https://github.com/adafruit/Adafruit_SSD1306

//Create an instance of class LSM6DS3
LSM6DS3 myIMU(I2C_MODE, 0x6A);  //I2C device address 0x6A

//Create an instance of the neopixel class
#define NEOPIXEL_PIN (10)
Adafruit_NeoPixel pixels = Adafruit_NeoPixel(NUM_PIXELS, NEOPIXEL_PIN, NEO_GRB + NEO_KHZ800);

//Create an instance of the SSD1306 display
constexpr uint8_t kDisplayWidth{ 128 };
constexpr uint8_t kDisplayHeight{ 64 };
constexpr int8_t kOledReset{ -1 };  // No Reset Pin
Adafruit_SSD1306 display(kDisplayWidth, kDisplayHeight, &Wire, kOledReset);

#define WHITE_LIMIT 3
#define PURPLE_LIMIT 5
#define BLUE_LIMIT 10
#define AQUA_LIMIT 15
#define GREEN_LIMIT 20
#define YELLOW_LIMIT 25
#define RED_LIMIT 30
const uint32_t kColorRed = Adafruit_NeoPixel::Color(64, 0, 0); 
const uint32_t kColorYellow = Adafruit_NeoPixel::Color(64, 64, 0); 
const uint32_t kColorGreen = Adafruit_NeoPixel::Color(0, 64, 0);
const uint32_t kColorAqua = Adafruit_NeoPixel::Color(0, 64, 64);
const uint32_t kColorBlue = Adafruit_NeoPixel::Color(0, 0, 64);
const uint32_t kColorPurple = Adafruit_NeoPixel::Color(64, 0, 64);
const uint32_t kColorWhite = Adafruit_NeoPixel::Color(32, 32, 32);

//persistent variable for time
unsigned long m_last_time = 0;
float m_roll = 0;
float m_pitch = 0;

/**
 * displays IMU data on lcd
 * @g_x - gyroscope x component
 * @g_y - gyroscope y component
 * @g_z - gyroscope z component
 * @a_x - accelerometer x component
 * @a_y - accelerometer y component
 * @a_z - accelerometer z component
 * roll - roll angle
 * pitch - pitch angle
*/
void display_imu(float g_x, float g_y, float g_z, float a_x, float a_y, float a_z, float roll, float pitch) {
  // Clear the buffer
  display.clearDisplay();
  // Set text color to white
  display.setTextColor(SSD1306_WHITE);
  // Set cursor position (column, row)
  display.setCursor(0, 0);
  // Set text size
  display.setTextSize(1);
  display.printf("LEVEL\r\n");

  display.setCursor(0, 16);
  // Set text size
  display.setTextSize(1);
  // Print text
  display.printf("G: %+3.2f %+3.2f %+3.2f\r\n", g_x, g_y, g_z);
  display.printf("A: %+3.2f %+3.2f %+3.2f\r\n", a_x, a_y, a_z);

  display.printf("ROLL : %+3.2f\r\n", roll);
  display.printf("PITCH: %+3.2f\r\n", pitch);

  display.display();
}

/**
 * displays roll and pitch on pixels based on value
 * left and right leds will depict pitch value
 * up and down leds will depict roll value
 * @roll - roll and in degrees
 * @pitch - pitch angle in degrees
 */
void display_pixel_level(float roll, float pitch){
  bool roll_neg = roll < 0;
  float roll_abs = fabs(roll);
  uint32_t roll_color = 0;

  bool pitch_neg = pitch < 0;
  float pitch_abs = fabs(pitch);
  uint32_t pitch_color = 0;

  if(roll_abs < WHITE_LIMIT){
    roll_color = kColorWhite;
  } else if(roll_abs < PURPLE_LIMIT){
    roll_color = kColorPurple;
  } else if(roll_abs < BLUE_LIMIT){
    roll_color = kColorBlue;
  } else if(roll_abs < AQUA_LIMIT){
    roll_color = kColorAqua;
  } else if(roll_abs < GREEN_LIMIT){
    roll_color = kColorGreen;
  } else if(roll_abs < YELLOW_LIMIT){
    roll_color = kColorYellow;
  } else {
    roll_color = kColorRed;    
  }

  if(pitch_abs < WHITE_LIMIT){
    pitch_color = kColorWhite;
  } else if(pitch_abs < PURPLE_LIMIT){
    pitch_color = kColorPurple;
  } else if(pitch_abs < BLUE_LIMIT){
    pitch_color = kColorBlue;
  } else if(pitch_abs < AQUA_LIMIT){
    pitch_color = kColorAqua;
  } else if(pitch_abs < GREEN_LIMIT){
    pitch_color = kColorGreen;
  } else if(pitch_abs < YELLOW_LIMIT){
    pitch_color = kColorYellow;
  } else {
    pitch_color = kColorRed;    
  }

  Serial.printf("roll : %f %d %f %6x\r\n", roll, roll_neg, roll_abs, roll_color);
  Serial.printf("pitch: %f %d %f %6x\r\n", pitch, pitch_neg, pitch_abs, pitch_color);

  // //roll 
  if(roll_color == kColorWhite){
    pixels.setPixelColor(UP_PIXEL_IDX, roll_color);
    pixels.setPixelColor(DOWN_PIXEL_IDX, roll_color);
  }
  else if(roll_neg){
    pixels.setPixelColor(UP_PIXEL_IDX, roll_color);
    pixels.setPixelColor(DOWN_PIXEL_IDX, 0);
  } else {
    pixels.setPixelColor(UP_PIXEL_IDX, 0);
    pixels.setPixelColor(DOWN_PIXEL_IDX, roll_color);
  }

  //pitch
  if(pitch_color == kColorWhite){
    pixels.setPixelColor(LEFT_PIXEL_IDX, pitch_color);
    pixels.setPixelColor(RIGHT_PIXEL_IDX, pitch_color);
  } else if(pitch_neg){
    pixels.setPixelColor(LEFT_PIXEL_IDX, pitch_color);
    pixels.setPixelColor(RIGHT_PIXEL_IDX, 0);
  } else {
    pixels.setPixelColor(LEFT_PIXEL_IDX, 0);
    pixels.setPixelColor(RIGHT_PIXEL_IDX, pitch_color);
  }

  pixels.setPixelColor(CENTER_PIXEL_IDX, kColorWhite);
  pixels.show();
}

void setup() {
  // put your setup code here, to run once:
  Serial.begin(115200);

  // IMU
  if (myIMU.begin() != 0) {
    Serial.println("Device error");
  } else {
    Serial.println("Device OK!");
  }

  //  Initialize Display
  if (!display.begin(SSD1306_SWITCHCAPVCC, 0x3C)) {
    Serial.println(F("SSD1306 allocation failed"));
  }
}

void loop() {
  unsigned long current_time = micros();
  float dt = (current_time - m_last_time) / 1000000.0; // Convert to seconds
  m_last_time = current_time;

  float g_x = myIMU.readFloatGyroX();
  float g_y = myIMU.readFloatGyroY();
  float g_z = myIMU.readFloatGyroZ();

  float a_x = myIMU.readFloatAccelX();
  float a_y = myIMU.readFloatAccelY();
  float a_z = myIMU.readFloatAccelZ();

  Serial.print("\nGyroscope:\n");
  Serial.printf(" X1 = %+07.3f\r\n", g_x);
  Serial.printf(" Y1 = %+07.3f\r\n", g_y);
  Serial.printf(" Z1 = %+07.3f\r\n", g_z);
  Serial.print("\nAccelerometer:\n");
  Serial.printf(" X1 = %+07.3f\r\n", a_x);
  Serial.printf(" Y1 = %+07.3f\r\n", a_y);
  Serial.printf(" Z1 = %+07.3f\r\n", a_z);

  // Calculate accelerometer-derived angles (for pitch and roll)
  float accel_roll = atan2(a_y, a_z) * 180 / PI;
  float accel_pitch = atan2(-a_x, sqrt(a_y * a_y + a_z * a_z)) * 180 / PI;

  // Apply complementary filter
  float alpha = 0.98; // Adjust as needed
  m_roll = (1 - alpha) * (m_roll + g_x * dt * 180 / PI) + alpha * accel_roll;
  m_pitch = (1 - alpha) * (m_pitch + g_y * dt * 180 / PI) + alpha * accel_pitch;

  display_imu(g_x, g_y, g_z, a_x, a_y, a_z, m_roll, m_pitch);
  display_pixel_level(m_roll, m_pitch);

  Serial.print("Roll: ");
  Serial.print(m_roll);
  Serial.print("\tPitch: ");
  Serial.println(m_pitch);

  delay(10); // Small delay for stability
}

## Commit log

2026-05-04 add electrical files
    [219 PCB Ruler v1 BOM.xlsx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]
2026-05-04 add firmware and examples
    [219 PCB Ruler v1 BOM - Digital Level.xlsx, 219 PCB Ruler v1 BOM - Simon.xlsx]
2026-05-05 update readme, add bare boards photos
2026-05-05 link bare board photo in readme
2026-05-05 update wiring diagrams
2026-05-05 Update README.md
    https://github.com/219-design/219-pcb-ruler/tree/init#known-issues
2026-05-05 add trademark mention for Simon
    [219 PCB Ruler v1 XY_PickPlace.csv]
